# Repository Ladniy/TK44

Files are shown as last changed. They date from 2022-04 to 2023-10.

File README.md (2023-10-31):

Title Image

Wireless ergo unibody split keyboard, based on [Holyiot-18010 (nRF52840)](http://www.holyiot.com/tp/2019042516322180424.pdf) module.

* __Author:__ [@ladniys (Telegram)](https://t.me/ladniys) [u/Ladniy (Reddit)](https://reddit.com/u/Ladniy)
* __Layout:__ [keyboard-layout-editor.com](http://www.keyboard-layout-editor.com/#/gists/4b6c2af67148f58ddd6c6b2976c4370f) (actually same as [Jian's](https://github.com/KGOH/Jian-Info))
* __Hardware Availability:__ [Open Source](https://github.com/Ladniy/TK44/releases/tag/v1.0.0)
* __Firmware:__ [ZMK](https://zmk.dev/)

Check out [wiki-page](https://github.com/Ladniy/TK44/wiki) for more information.

## Photos

Main Photo

**See more photos on [Imgur](https://imgur.com/a/DaCdFm3)**

## Project status

**The keyboard is fully functional, no problems were noticed.**

## License

This project is licensed under a [CERN-OHL-P v2.0](https://ohwr.org/project/cernohl/wikis/Documents/CERN-OHL-version-2).

Feel free to use, share, modify or even sell TK44!

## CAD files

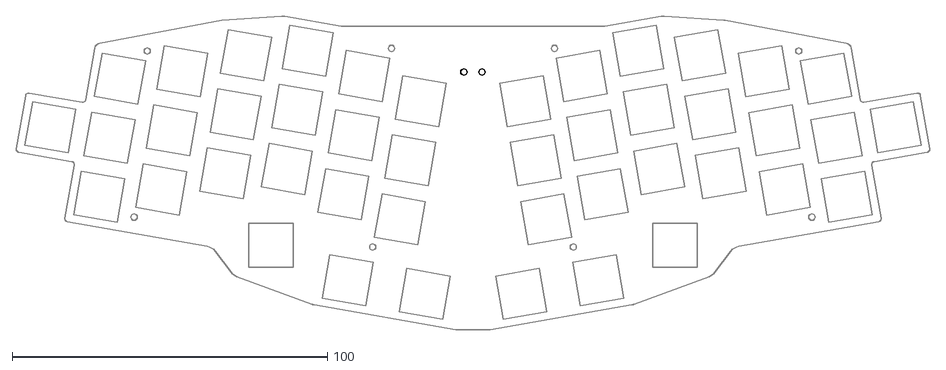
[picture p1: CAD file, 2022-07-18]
case/other-materials/plate.dxf
290.0 x 99.6

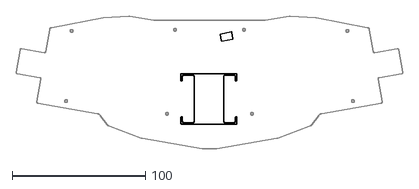
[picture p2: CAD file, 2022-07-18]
case/other-materials/bottom.dxf
290.0 x 99.6

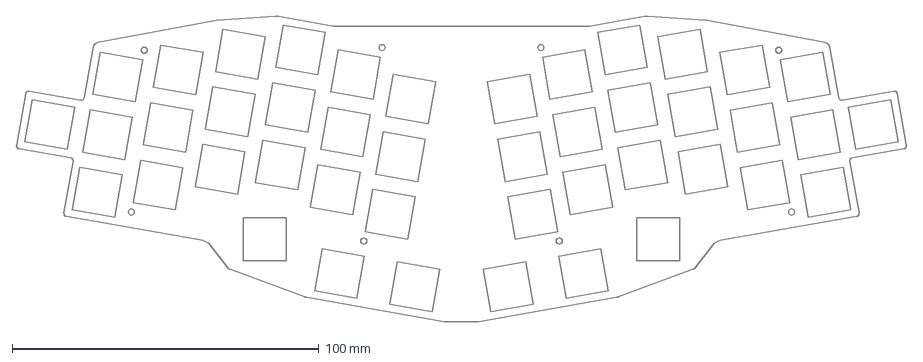
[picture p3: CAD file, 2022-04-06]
case/other-materials/source.dxf
290.0 x 99.6 mm

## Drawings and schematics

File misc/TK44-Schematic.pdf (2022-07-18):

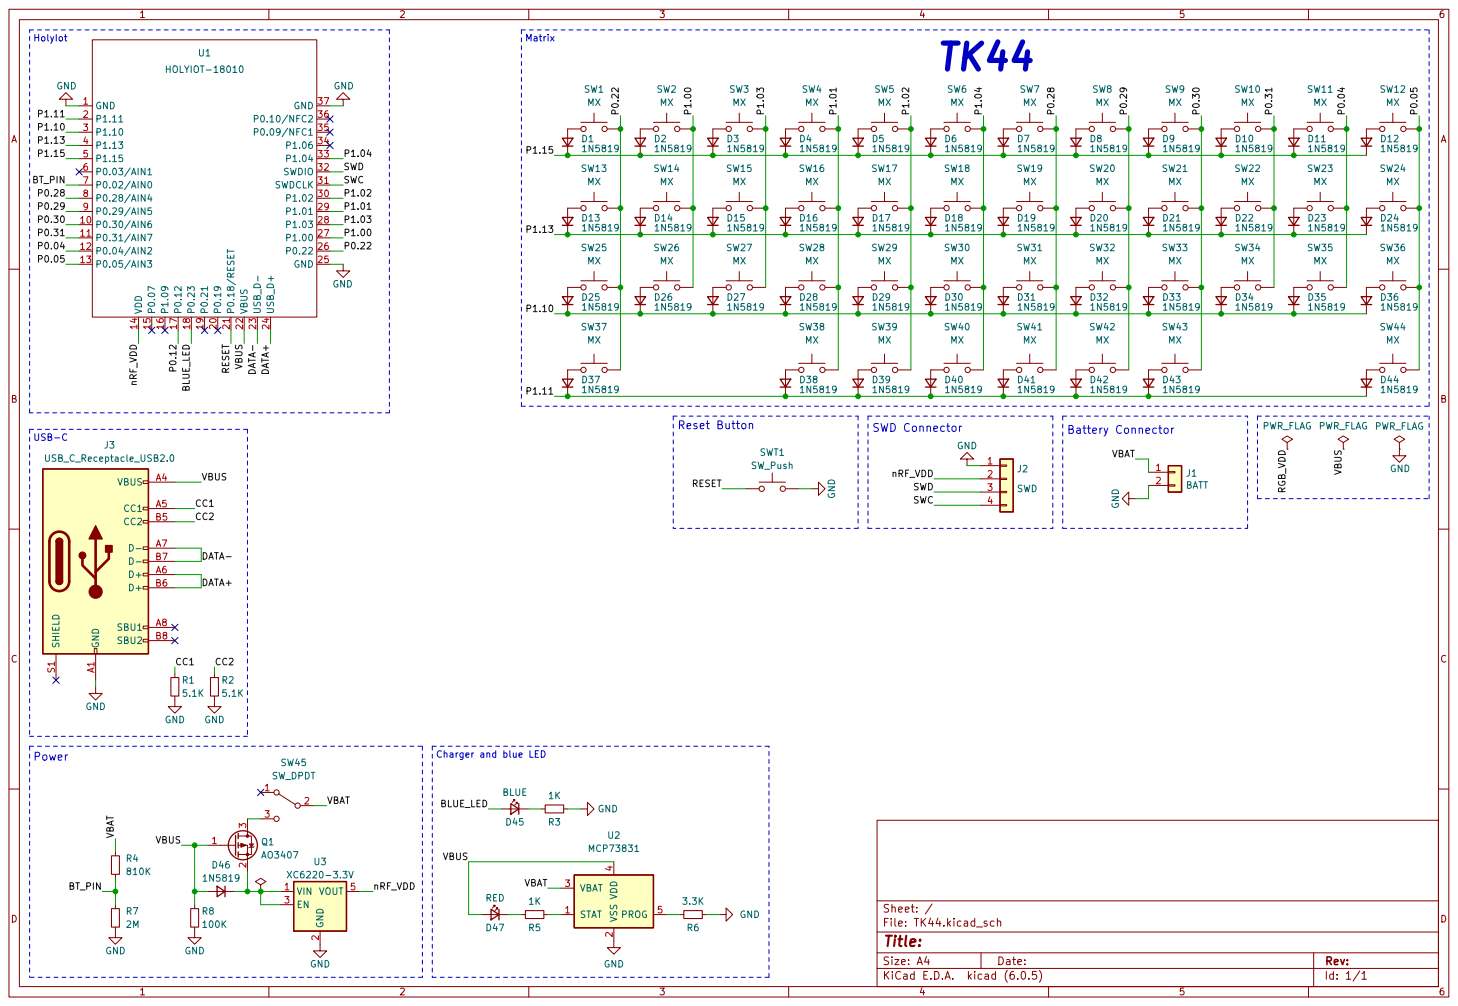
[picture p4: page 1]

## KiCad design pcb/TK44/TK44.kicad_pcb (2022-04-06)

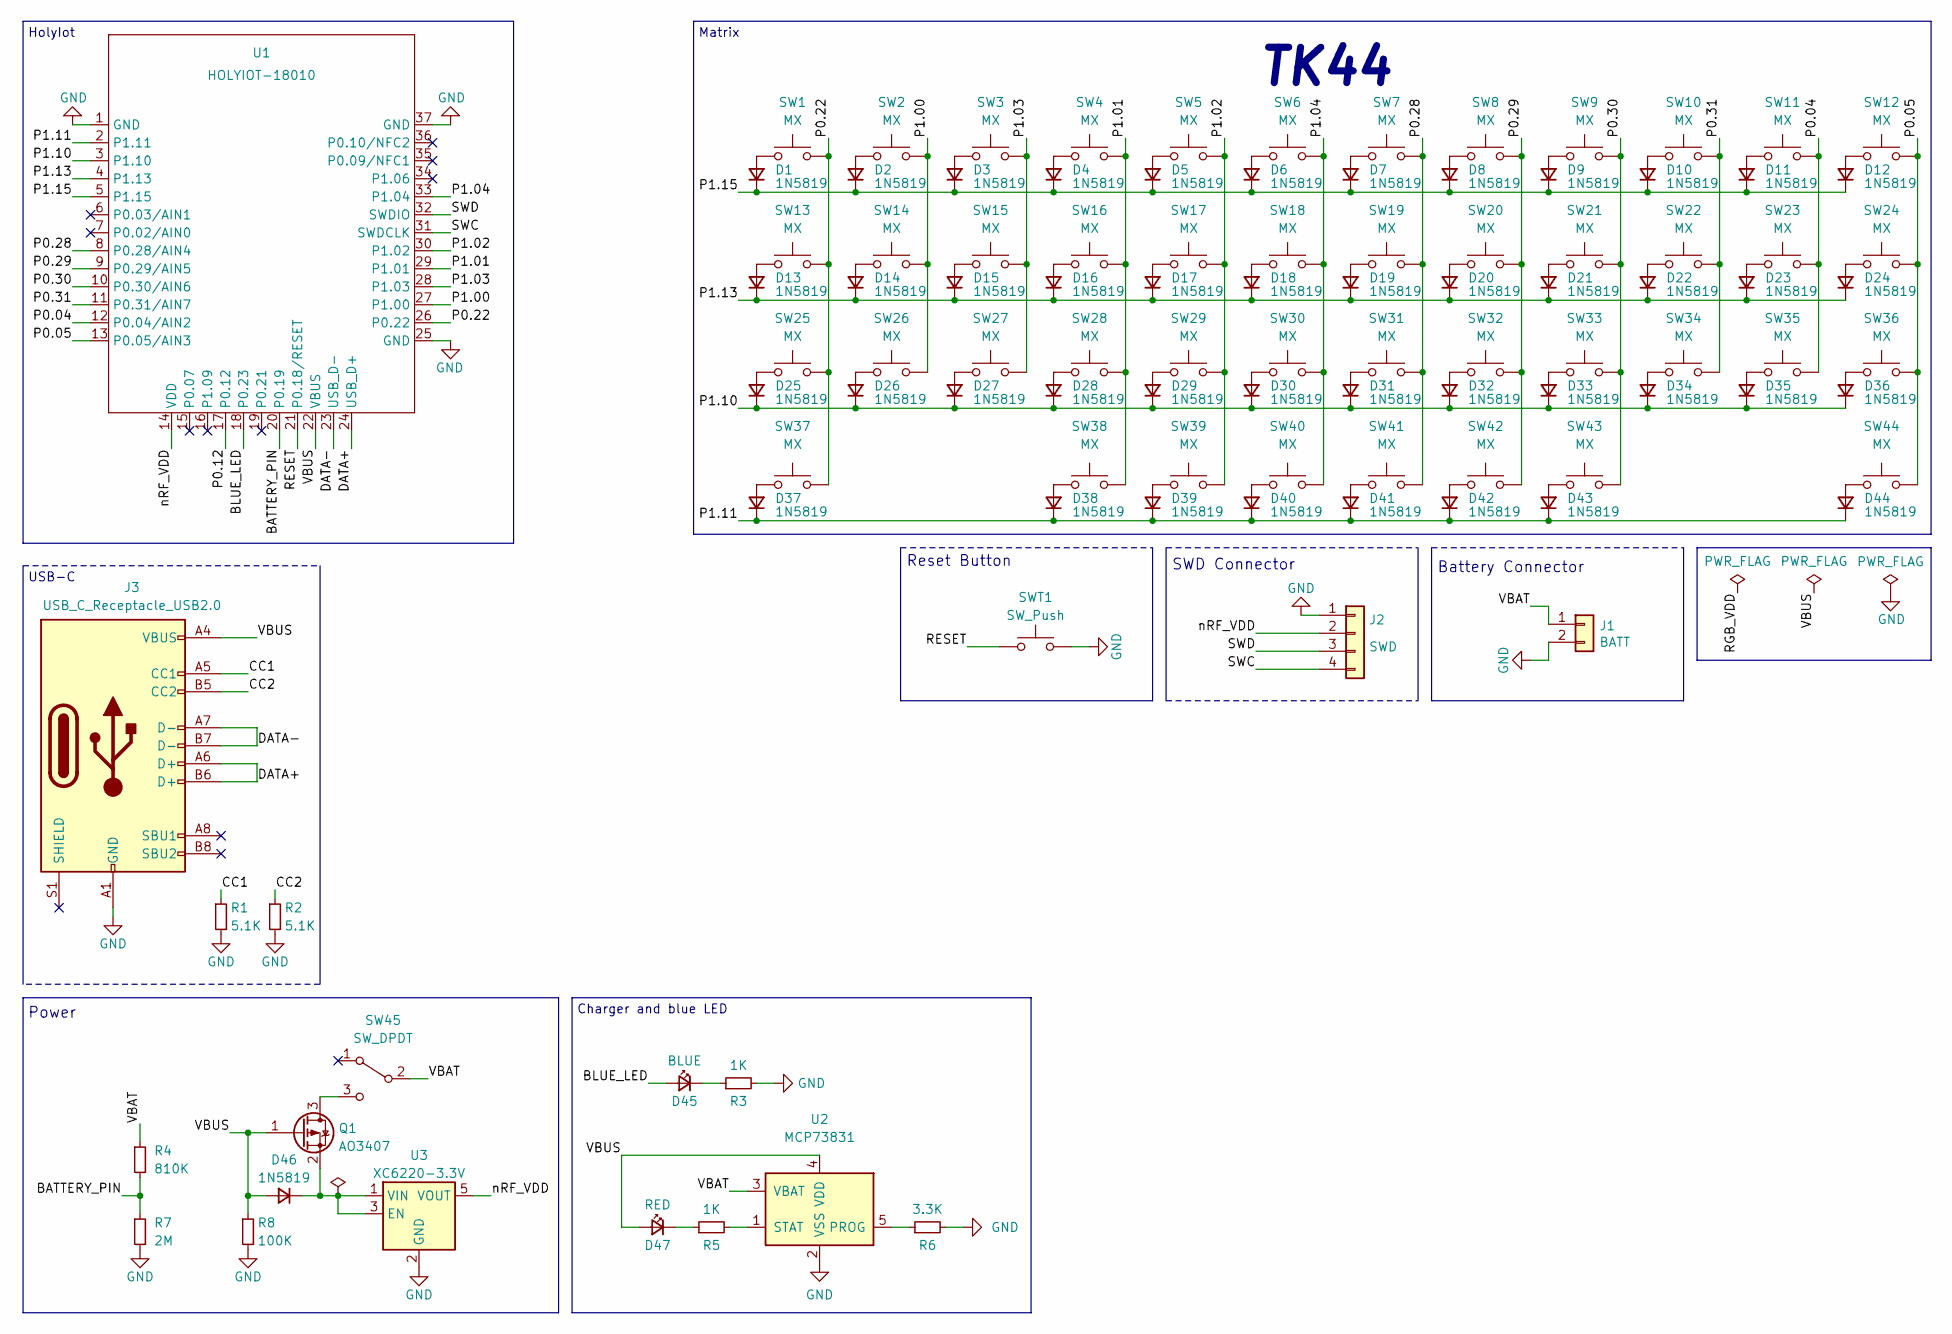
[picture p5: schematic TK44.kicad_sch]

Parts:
D1, D2, D3, D4, D5, D6, D7, D8, D9, D10, D11, D12, D13, D14, D15, D16, D17, D18, D19, D20, D21, D22, D23, D24, D25, D26, D27, D28, D29, D30, D31, D32, D33, D34, D35, D36, D37, D38, D39, D40, D41, D42, D43, D44, D46: 1N5819; D_SOD-123
D45: BLUE; LED_0603
D47: RED; LED_0603
J1: BATT; Battery_Connector
J2: SWD; Connector_THT_1x4_2.54
J3: USB_C_Receptacle_USB2.0; USB-C-C168688
Q1: AO3407; SOT-23
R1, R2: 5.1K; R_0603
R3, R5: 1K; R_0603
R4: 810K; R_0603
R6: 3.3K; R_0603
R7: 2M; R_0603
R8: 100K; R_0603
SW1, SW2, SW3, SW4, SW5, SW6, SW7, SW8, SW9, SW10, SW11, SW12, SW13, SW14, SW15, SW16, SW17, SW18, SW19, SW20, SW21, SW22, SW23, SW24, SW25, SW26, SW27, SW28, SW29, SW30, SW31, SW32, SW33, SW34, SW35, SW36, SW37, SW39, SW42, SW44: MX; Switch_Mx_Hotswap_1u
SW38, SW40, SW41, SW43: MX; Switch_Mx_Hotswap_1.25u
SW45: SW_DPDT; MSK-12C02
SWT1: SW_Push; K2-1187SQ
U1: HOLYIOT-18010; Holyiot-18010-nRF52840
U2: MCP73831; SOT-23-5
U3: XC6220-3.3V; SOT-23-5

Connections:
/BATTERY_PIN: R4.2, R7.1, U1.20 (P0.19)
/BLUE_LED: D45.2 (A), U1.18 (P0.23)
/CC1: J3.A5 (CC1), R1.1
/CC2: J3.B5 (CC2), R2.1
/DATA+: J3.A6 (D+), J3.B6 (D+), U1.24 (USB_D+)
/DATA-: J3.A7 (D-), J3.B7 (D-), U1.23 (USB_D-)
/P0.04: SW11.2, SW23.2, SW35.2, U1.12 (P0.04/AIN2)
/P0.05: SW12.2, SW24.2, SW36.2, SW44.2, U1.13 (P0.05/AIN3)
/P0.12: U1.17 (P0.12)
/P0.22: SW1.2, SW13.2, SW25.2, SW37.2, U1.26 (P0.22)
/P0.28: SW7.2, SW19.2, SW31.2, SW41.2, U1.8 (P0.28/AIN4)
/P0.29: SW8.2, SW20.2, SW32.2, SW42.2, U1.9 (P0.29/AIN5)
/P0.30: SW9.2, SW21.2, SW33.2, SW43.2, U1.10 (P0.30/AIN6)
/P0.31: SW10.2, SW22.2, SW34.2, U1.11 (P0.31/AIN7)
/P1.00: SW2.2, SW14.2, SW26.2, U1.27 (P1.00)
/P1.01: SW4.2, SW16.2, SW28.2, SW38.2, U1.29 (P1.01)
/P1.02: SW5.2, SW17.2, SW29.2, SW39.2, U1.30 (P1.02)
/P1.03: SW3.2, SW15.2, SW27.2, U1.28 (P1.03)
/P1.04: SW6.2, SW18.2, SW30.2, SW40.2, U1.33 (P1.04)
/P1.10: D25.1 (K), D26.1 (K), D27.1 (K), D28.1 (K), D29.1 (K), D30.1 (K), D31.1 (K), D32.1 (K), D33.1 (K), D34.1 (K), D35.1 (K), D36.1 (K), U1.3 (P1.10)
/P1.11: D37.1 (K), D38.1 (K), D39.1 (K), D40.1 (K), D41.1 (K), D42.1 (K), D43.1 (K), D44.1 (K), U1.2 (P1.11)
/P1.13: D13.1 (K), D14.1 (K), D15.1 (K), D16.1 (K), D17.1 (K), D18.1 (K), D19.1 (K), D20.1 (K), D21.1 (K), D22.1 (K), D23.1 (K), D24.1 (K), U1.4 (P1.13)
/P1.15: D1.1 (K), D2.1 (K), D3.1 (K), D4.1 (K), D5.1 (K), D6.1 (K), D7.1 (K), D8.1 (K), D9.1 (K), D10.1 (K), D11.1 (K), D12.1 (K), U1.5 (P1.15)
/RESET: SWT1.1, U1.21 (P0.18/RESET)
/SWC: J2.4, U1.31 (SWDCLK)
/SWD: J2.3, U1.32 (SWDIO)
/VBAT: J1.1, R4.1, SW45.2, U2.3 (VBAT)
/VBUS: D46.2 (A), D47.2 (A), J3.A4 (VBUS), J3.A9 (VBUS), J3.B4 (VBUS), J3.B9 (VBUS), Q1.1 (G), R8.1, U1.22 (VBUS), U2.4 (VDD)
/nRF_VDD: J2.2, U1.14 (VDD), U3.5 (VOUT)
GND: J1.2, J2.1, J3.A1 (GND), J3.A12 (GND), J3.B1 (GND), J3.B12 (GND), R1.2, R2.2, R3.2, R6.2, R7.2, R8.2, SWT1.2, U1.1 (GND), U1.25 (GND), U1.37 (GND), U2.2 (VSS), U3.2 (GND)
unnamed: D1.2 (A), SW1.1
unnamed: D2.2 (A), SW2.1
unnamed: D3.2 (A), SW3.1
unnamed: D4.2 (A), SW4.1
unnamed: D5.2 (A), SW5.1
unnamed: D6.2 (A), SW6.1
unnamed: D7.2 (A), SW7.1
unnamed: D8.2 (A), SW8.1
unnamed: D9.2 (A), SW9.1
unnamed: D10.2 (A), SW10.1
unnamed: D11.2 (A), SW11.1
unnamed: D12.2 (A), SW12.1
unnamed: D13.2 (A), SW13.1
unnamed: D14.2 (A), SW14.1
unnamed: D15.2 (A), SW15.1
unnamed: D16.2 (A), SW16.1
unnamed: D17.2 (A), SW17.1
unnamed: D18.2 (A), SW18.1
unnamed: D19.2 (A), SW19.1
unnamed: D20.2 (A), SW20.1
unnamed: D21.2 (A), SW21.1
unnamed: D22.2 (A), SW22.1
unnamed: D23.2 (A), SW23.1
unnamed: D24.2 (A), SW24.1
unnamed: D25.2 (A), SW25.1
unnamed: D26.2 (A), SW26.1
unnamed: D27.2 (A), SW27.1
unnamed: D28.2 (A), SW28.1
unnamed: D29.2 (A), SW29.1
unnamed: D30.2 (A), SW30.1
unnamed: D31.2 (A), SW31.1
unnamed: D32.2 (A), SW32.1
unnamed: D33.2 (A), SW33.1
unnamed: D34.2 (A), SW34.1
unnamed: D35.2 (A), SW35.1
unnamed: D36.2 (A), SW36.1
unnamed: D37.2 (A), SW37.1
unnamed: D38.2 (A), SW38.1
unnamed: D39.2 (A), SW39.1
unnamed: D40.2 (A), SW40.1
unnamed: D41.2 (A), SW41.1
unnamed: D42.2 (A), SW42.1
unnamed: D43.2 (A), SW43.1
unnamed: D44.2 (A), SW44.1
unnamed: D45.1 (K), R3.1
unnamed: D46.1 (K), Q1.2 (S), U3.1 (VIN), U3.3 (EN)
unnamed: D47.1 (K), R5.1
unnamed: Q1.3 (D), SW45.3
unnamed: R5.2, U2.1 (STAT)
unnamed: R6.1, U2.5 (PROG)

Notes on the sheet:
HolyIot
USB-C
Power
TK44
SWD Сonnector
Reset Button
Battery Сonnector
Charger and blue LED
Matrix

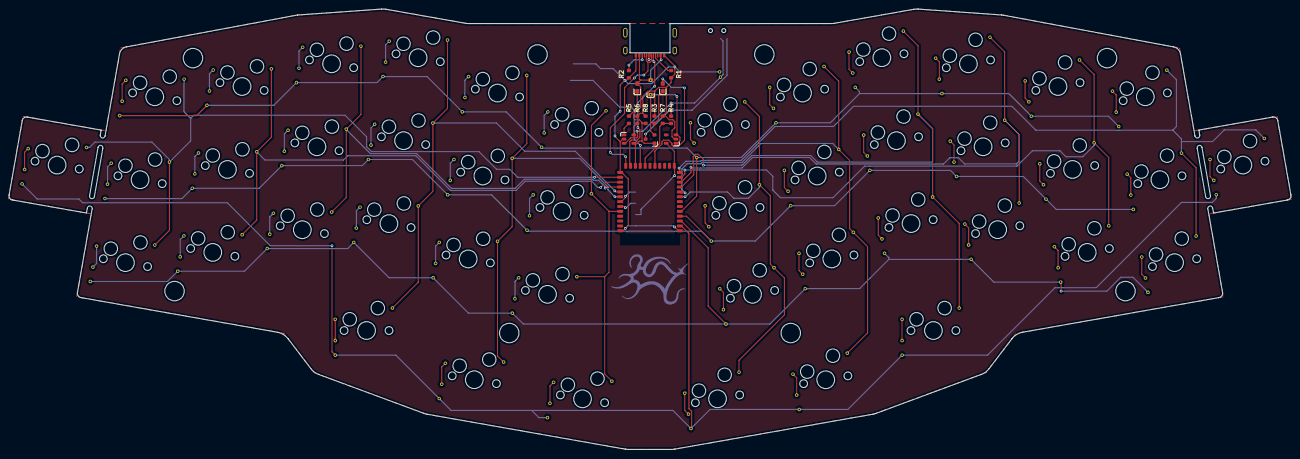
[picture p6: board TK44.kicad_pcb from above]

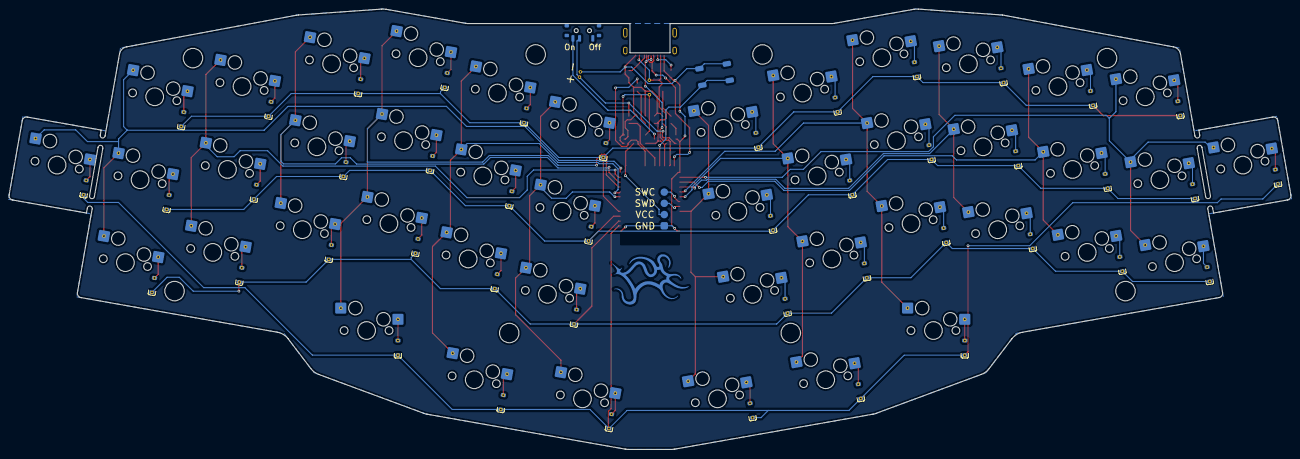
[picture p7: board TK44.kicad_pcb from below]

Board: 2 copper layers, 289.9 x 99.6 mm, 117 parts (48 on the bottom side), 79 nets.

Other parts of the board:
H1, H2, H3, H4, H5, H6, H7, H8: Hole_Mount_M4
LOGO1: LOGO; logo

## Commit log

2022-03-28 Create project & complete schematic
    [TK44.kicad_pcb, TK44.kicad_sch]
2022-03-28 Plot schematic
2022-04-06 No comment /////
    [TK44-CuBottom.gbr, TK44-CuTop.gbr, TK44-EdgeCuts.gbr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]
2022-04-06 Fix silkscreen clearance
2022-04-06 Fix DRC errors and silk overlapping
    [TK44.kicad_pcb]
2022-04-06 Update logo footprint & refill zones
2022-04-07 Design fr-4 bottom
    [bottom.kicad_pcb]
2022-04-07 Design fr-4 plate
    [plate.kicad_pcb]
2022-04-08 Plot gerbers
    [TK44-B_Cu.gbl, TK44-B_Mask.gbs, TK44-B_Paste.gbp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]
2022-04-19 Plot new gerbers
    [TK44-B_Cu.gbl, TK44-B_Mask.gbs, TK44-B_Paste.gbp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]
2022-04-19 Just a little fix
    [bottom.kicad_pcb, plate.kicad_pcb]
2022-04-19 Plot new schematic pdf
2022-05-27 Change battery pin
    [TK44.kicad_sch]
2022-05-27 Route track for battery pin
2022-07-18 Update gerbers
    [TK44-B_Cu.gbl, TK44-B_Mask.gbs, TK44-B_Paste.gbp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]
2022-07-18 Update logo footprint and pdf of schematic
2022-07-18 Design dxf files for case
    [bottom.dxf, plate.dxf]
2022-07-18 Update PCB
2022-08-28 Remove gerbers files and rename zip archive
    [TK44-B_Cu.gbl, TK44-B_Mask.gbs, TK44-B_Silkscreen.gbo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]
2022-08-28 Move files for case
    [bottom.dxf, plate.dxf, source.dxf]
2022-08-28 Create global misc catalog and move schematic pdf there
2023-01-19 Little change in silkscreen
